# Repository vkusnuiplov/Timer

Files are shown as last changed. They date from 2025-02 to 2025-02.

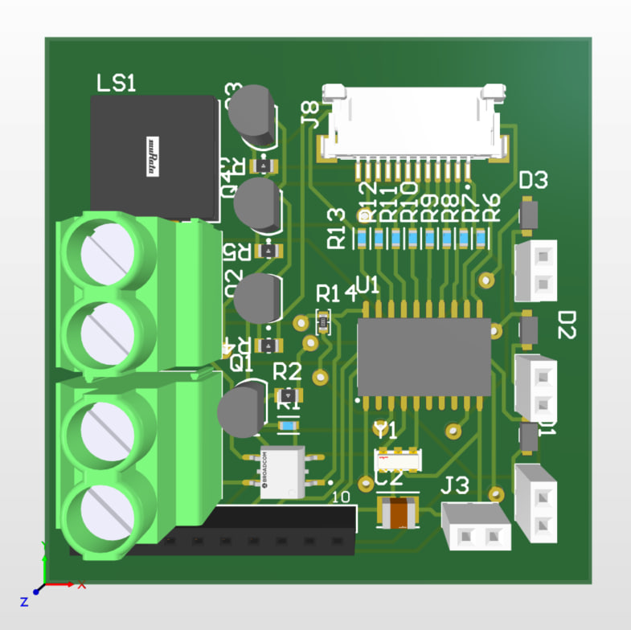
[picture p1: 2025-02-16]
Images/3d.jpg

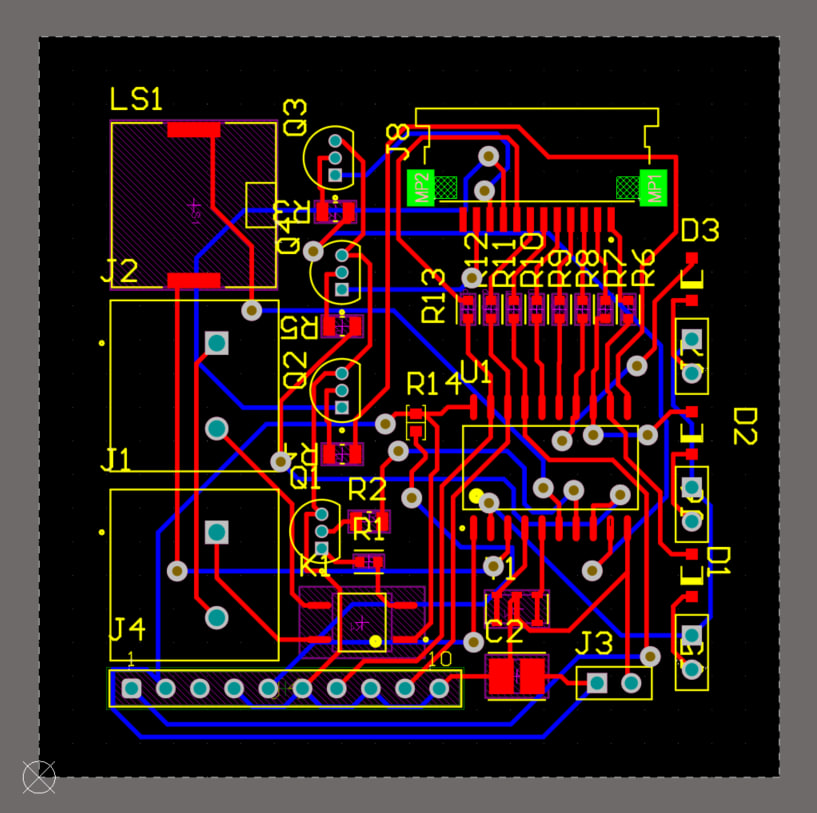
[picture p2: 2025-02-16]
Images/Pcb.jpg

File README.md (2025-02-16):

# Timer based on ATtiny 2313 microcontroller

## Description
This project is a timer using the ATtiny 2313 microcontroller. It controls an AC load (230V), turning it on for a set time and then turning it off automatically when the time ends. This can be used to control things like lights or appliances that need to work for a certain period. The ATtiny 2313 is small and uses little power, which makes it great for timing tasks.

## PCB and 3D-Design

<p align="center">
    <table width="100%">
        <tr>
            <td style="border: 1px solid black; padding: 10px; text-align:center; width: 50%; box-sizing: border-box;">
                <div style="text-align: center;"><b>3D-Design</b></div>
            </td>
            <td style="border: 1px solid black; padding: 10px; text-align:center; width: 50%; box-sizing: border-box;">
                <div style="text-align: center;"><b>PCB</b></div>
            </td>
        </tr>
        <tr>
            <td style="border: 1px solid black; padding: 10px; text-align:center; width: 90%; box-sizing: border-box;">
                
            </td>
            <td style="border: 1px solid black; padding: 10px; text-align:center; width: 90%; box-sizing: border-box;">
                
            </td>
        </tr>
    </table>
</p>

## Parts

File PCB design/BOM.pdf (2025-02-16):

Перш. застос

Форм.
Зона
Поз.
Позначення | Найменування

Кіл.
Прим.
| Документація
А1 | ФКІСІТ 171.016.024.Е1 | Схема електрична принципова | 1
А1 | ФКІСІТ 171.016.024.Е3 | Схема електрична структурна | 1
А4 | ФКІСІТ 171.016.024.ПЕ3 | Перелік елементів | 1
А4 | ФКІСІТ 171.016.024.ПЗ | Пояснювальна записка | 1
А1 | ФКІСІТ 171.016.024.СК | Складальне креслення | 1

Справ. №

Деталі

1 | ФКІСІТ 171.016.024.001 | Плата друкована | 1

Інші вироби

Підп. та дата

Конденсатори

2 | C1 | 10uF 25V | 1

Інв. № дубл.

| | Мікросхеми

Зам. Інв. №
3 | DD1 | ATtiny2313-20SU | 1

П’єзодинаміки

Підп. та дата

4 | HA1 | PKLCS1212E2000-R1 | 1

Індикатори

Інв. № дійсн.

# ФКІСІТ 171.016.024

Змін. | Арк. | № докум. | Підпис | Дата
Розроб. | Розумнюк К. С.

Таймер зі зворотнім відліком

Літ. | Арк. | Аркушів
Перев. | Савченко М. Г | 1 | 3
Н.контр. | Домрачев О. М. | 451
Затверд. | Савченко М. Г

Перш. застос

Прим. 5 | HG1 | KEM-3631-ASR_448 | 1

Реле

Справ. №

6 | KV1 | ASSR-4110-003E

1

Кварцеві резонатори

7 | Q1 | CSTCR4M00G53-R0

1

Резистори

Підп. та дата

8 | R1 | CS060310K0JNEA | 1
9 | R2-R9, R14 | RK73H1JTTD1000F | 9
10 | R10-R13 | CRCW08056K80FKEA | 4

Інв. № дубл.
Кнопки
11 | SB1-SB3

1-1825027-

1

3

Зам. Інв. №

Діоди

Підп. та дата

12 | VD1-VD3 | 1N4148W- 7-

F

3

Транзистори

Інв. № дійсн.

13 | VT1-VT4 | BC547B

4

Роз’єми

# ФКІСІТ 171.016.024

Арк.2

Змін. | Арк. | № докум. | Підпис | Дата

Перш. застос

Прим.

14 | XS1, XT1-XT3 | SSW-102-02-T-S | 4
15 | XS2, XS3 | 1714955 | 2
16 | XT4 | 61301011821 | 1
17 | XT5 | 52207-1260 | 1

Справ. №
Матеріали

Припій

18 | FELDER-Sn60Pb38Cu2

Флюс

Підп. та дата

19 | AVRGROUP MP218

Лак

Інв. № дубл.

20 | ЦАПОН 30

Зам. Інв. № Підп. та дата Інв. № дійсн.

# ФКІСІТ 171.016.024

Арк.3

Змін. | Арк. | № докум. | Підпис | Дата

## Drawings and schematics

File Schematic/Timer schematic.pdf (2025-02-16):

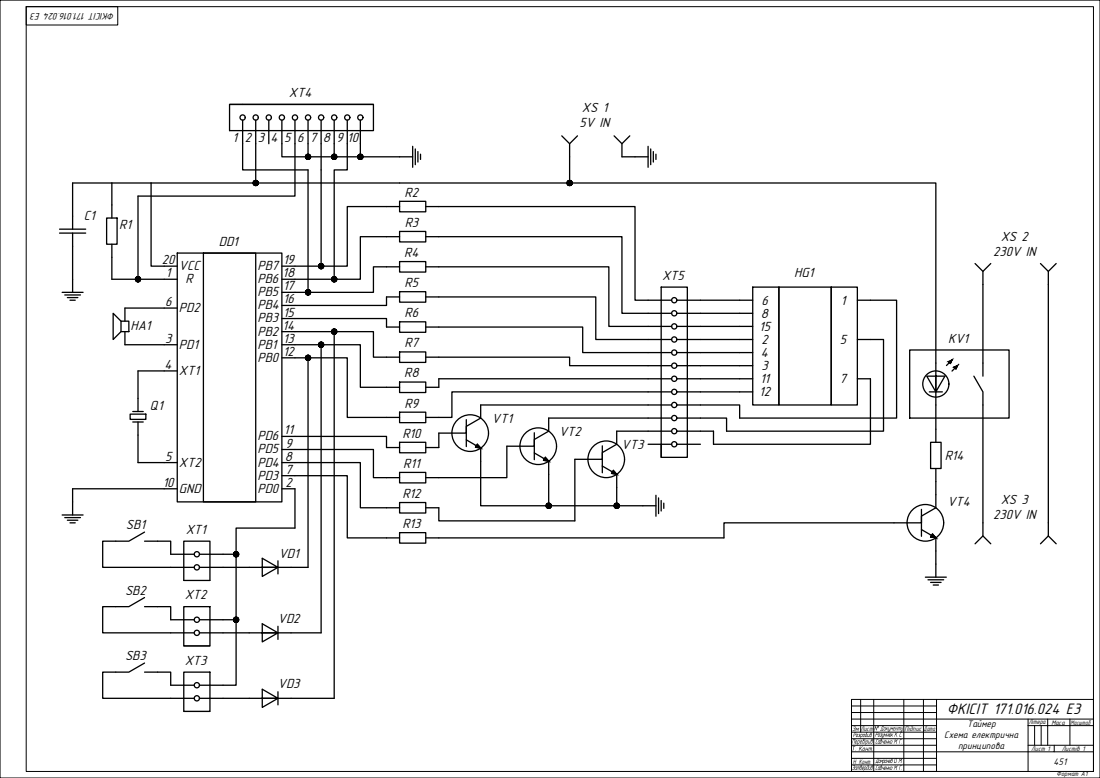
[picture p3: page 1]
XT5 PB7 PB6 PB5 PB4 PB3 PB2 PB1 PB0 XT1 PD2PD1 VCCR; DD1XT2 GND; 1918171615141312 119872 ФКІСІТ 171.016.024 Е3; Формат А1 ЗмРозробив Перевiрив Т. Конт. Н. Конт. Затвердив; Маса; Масштаб Лист № Документу Пiдпис Дата; Лiтера HA1; 451 Домрачев О. М. Розумнюк К. С. Савченко М. Г. Савченко М. Г.; ФКІСІТ 171.016.024 Е3 Таймер Схема електрична принципова; Лист 1; Листів 1

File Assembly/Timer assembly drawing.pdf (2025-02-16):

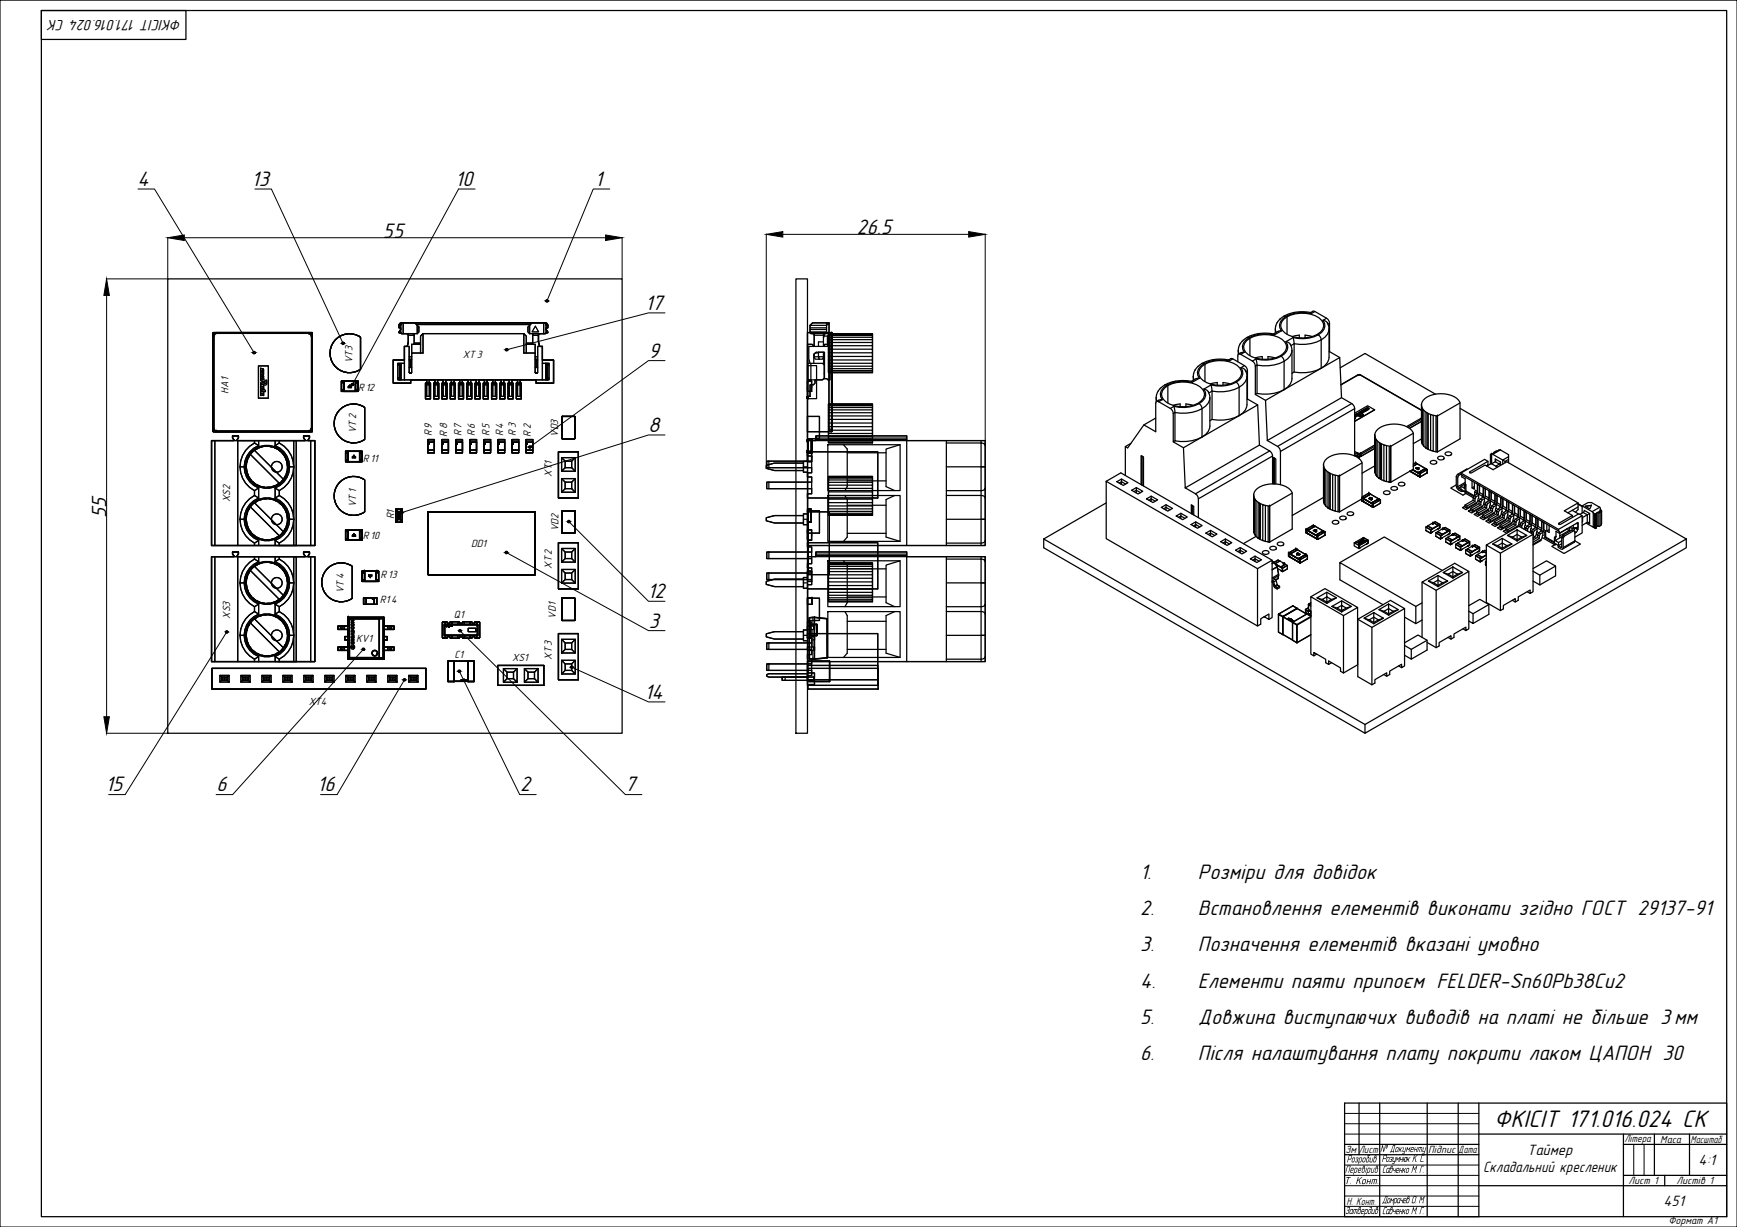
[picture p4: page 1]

55 55 26.5 12 1. Розміри для довідок 2. Встановлення елементів виконати згідно ГОСТ 29137-91 3. Позначення елементів вказані умовно 4. Елементи паяти припоєм FELDER-Sn60Pb38Cu2 5. Довжина виступаючих виводів на платі не більше 3 мм 6. Після налаштування плату покрити лаком ЦАПОН 30 451 Домрачев О. М. Розумнюк К. С. Савченко М. Г. Савченко М. Г. ФКІСІТ 171.016.024 СК Таймер Складальний кресленик Лист 1 Листів 1 4 13 10 1 179 8 3 14 15 6 16 2 7

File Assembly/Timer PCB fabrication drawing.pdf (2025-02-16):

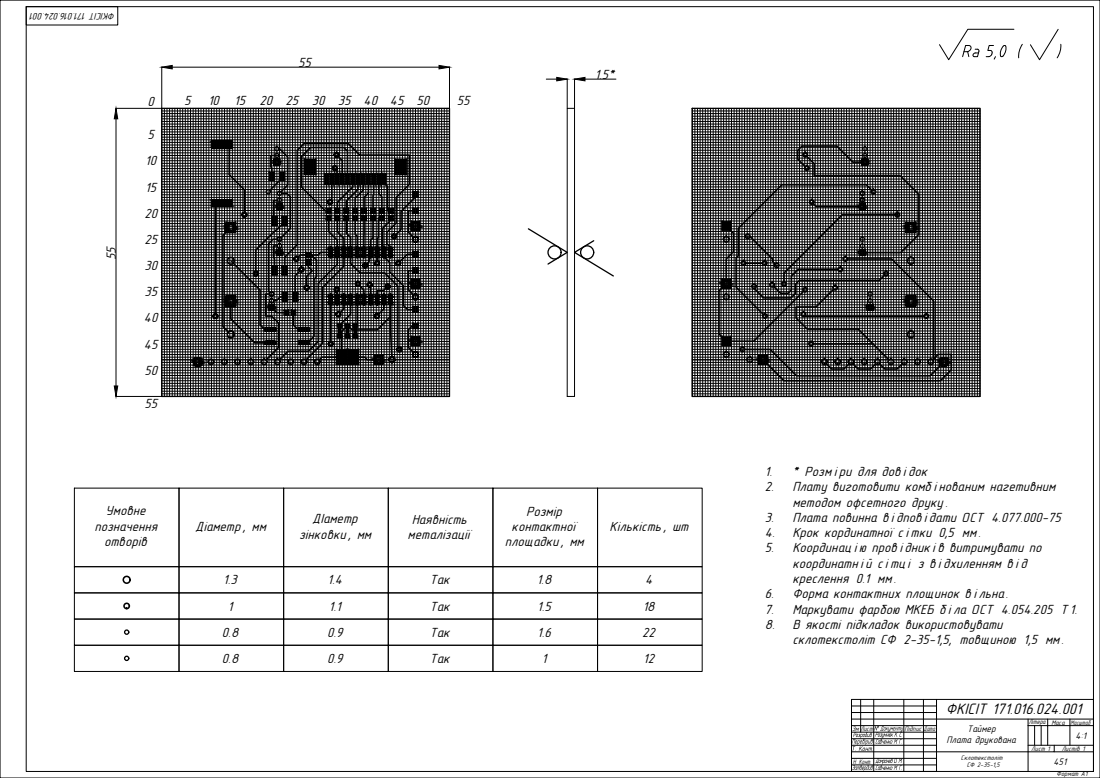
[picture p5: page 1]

55 1.5* Розмір контактної площадки , мм Кількість , шт ДІаметр зінковки , мм Наявність металізації Діаметр , мм Умовне позначення отворів 1.3 1.4 Так 1.8 4 1 1.1 Так 1.5 18 0.8 0.9 Так 1.6 22 0.8 0.9 Так 1 12 5 1520253035404550 10 0 55 5 10 15 20 25 30 35 40 45 50 55 1. * Розм i ри для дов i док 2. Плату виготовити комб i нованим нагетивним методом офсетного друку . 3. Плата повинна в i дпов i дати ОСТ 4.077.000-75 4. Крок кординатної с i тки 0,5 мм. 5. Координац i ю пров i дник i в витримувати по координатн i й с i тцi з в i дхиленням в i д креслення 0.1 мм. 6. Форма контактних площинок в i льна . 7. Маркувати фарбою МКЕБ б i ла ОСТ 4.054.205 Т 1. 8. В якості підкладок використовувати склотекстоліт СФ 2-35-1,5, товщиною 1,5 мм. 451 Домрачев О. М. Розумнюк К. С. Савченко М. Г. Савченко М. Г. ФКІСІТ 171.016.024.001 Таймер Плата друкована Склотекстоліт СФ 2-35-1,5 Лист 1 Листів 1
